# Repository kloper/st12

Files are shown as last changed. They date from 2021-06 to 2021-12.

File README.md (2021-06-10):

* README for ST12

I am working on my own soldering station based on HAKKO T12 cartriges. 
Electronics is related to the one found on EEVBlog forum
https://www.eevblog.com/forum/reviews/t12-stm32-v2-1s-soldering-station-controller-schematic-etc/

Firmware will be built from scratch.
Work in progress.

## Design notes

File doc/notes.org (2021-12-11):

* Unsorted Tasks

** TODO Disable station on overcurrent
   [2021-10-31 Sun 22:40]
   [[file:~/w/st12/firmware/st12_term.h::uint32_t current;]]

** TODO Move target temp increment to config
   [2021-10-31 Sun 22:51]
   [[file:~/w/st12/firmware/st12_term.c::config_set_target_temperature(config->target_temperature + 500);]]

* Notes for ST12 development

** Firmware work plan

  1. ADC in for I_SENSE
  2. ADC in for T_SENSE
  3. ADC in for cold junction thermistor
  4. Initial calibration for ADC inputs
  5. GPIO input for SHAKE_SENSE
  6. GPIO input for rotary encoder
  7. I2C interface with EEPROM
  8. I2C interface with Pato display controller
   
** Source of type-all.pdf

   https://www.tayloredge.com/reference/Tables/thermocouple01.pdf

** 24LC1052

I2C Address is 0x50 for block 0 and 0x54 for block 1
Address is 16 bit wide.
Write is 16bit address + data bytes
Read is 16bit address write + data bytes read

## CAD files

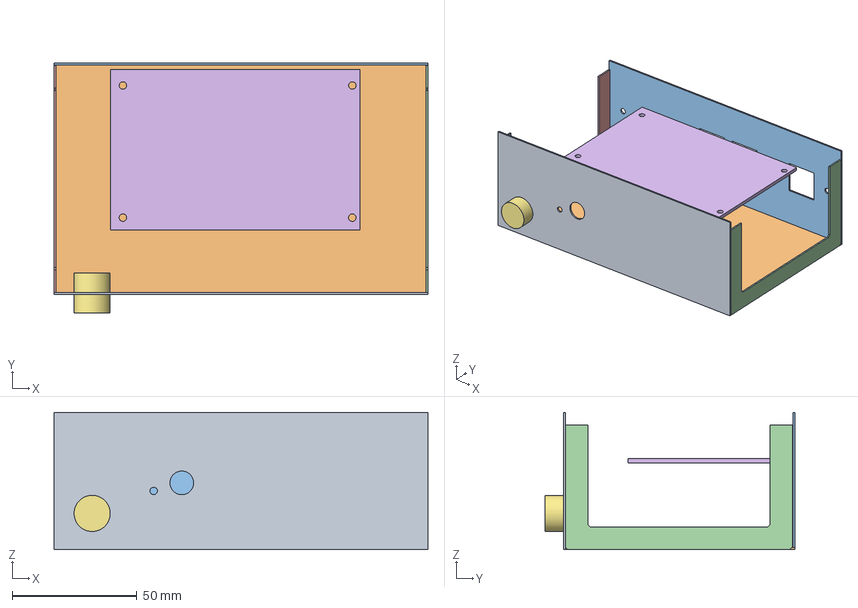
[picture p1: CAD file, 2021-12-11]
freecad/st12.FCStd
150.0 x 100.2 x 55.0 mm
front
bottom
back
right_side
left_side
pcb
heater

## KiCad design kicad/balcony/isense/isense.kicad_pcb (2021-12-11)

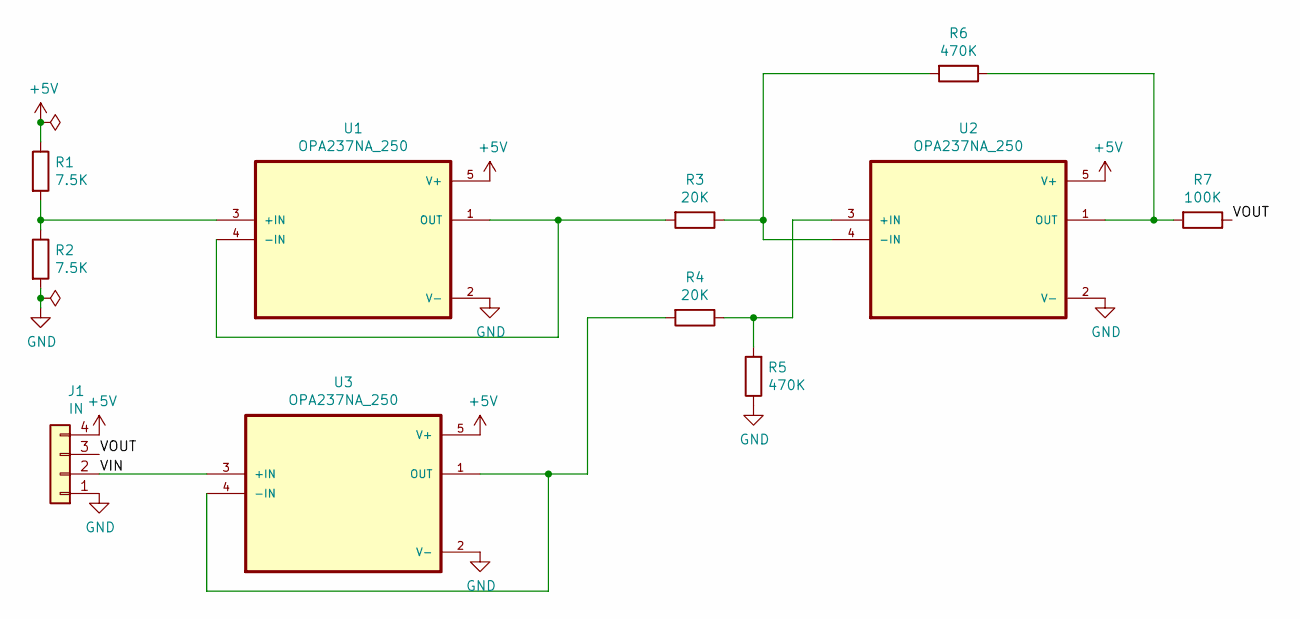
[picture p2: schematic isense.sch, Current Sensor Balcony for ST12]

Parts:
J1: IN; Pin_Header_Straight_1x04_Pitch2.54mm
R1, R2: 7.5K; R_0805_HandSoldering
R3, R4: 20K; R_0805_HandSoldering
R5, R6: 470K; R_1206_HandSoldering
R7: 100K; R_0805_2012Metric_Pad1.20x1.40mm_HandSolder
U1, U2, U3: OPA237NA_250; SOT95P280X145-5N

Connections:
+5V: J1.4, R1.1, U1.5 (V+), U2.5 (V+), U3.5 (V+)
/VIN: J1.2, U3.3 (+IN)
/VOUT: J1.3, R7.1
GND: J1.1, R2.2, R5.1, U1.2 (V-), U2.2 (V-), U3.2 (V-)
unnamed: R1.2, R2.1, U1.3 (+IN)
unnamed: R3.1, R6.2, U2.4 (-IN)
unnamed: R3.2, U1.1 (OUT), U1.4 (-IN)
unnamed: R4.1, R5.2, U2.3 (+IN)
unnamed: R4.2, U3.1 (OUT), U3.4 (-IN)
unnamed: R6.1, R7.2, U2.1 (OUT)

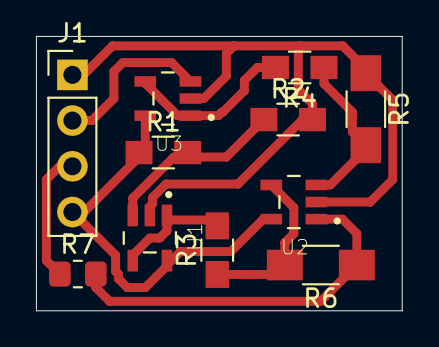
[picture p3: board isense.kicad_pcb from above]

Board: 2 copper layers, 20.3 x 15.2 mm, 11 parts (0 on the bottom side), 10 nets.

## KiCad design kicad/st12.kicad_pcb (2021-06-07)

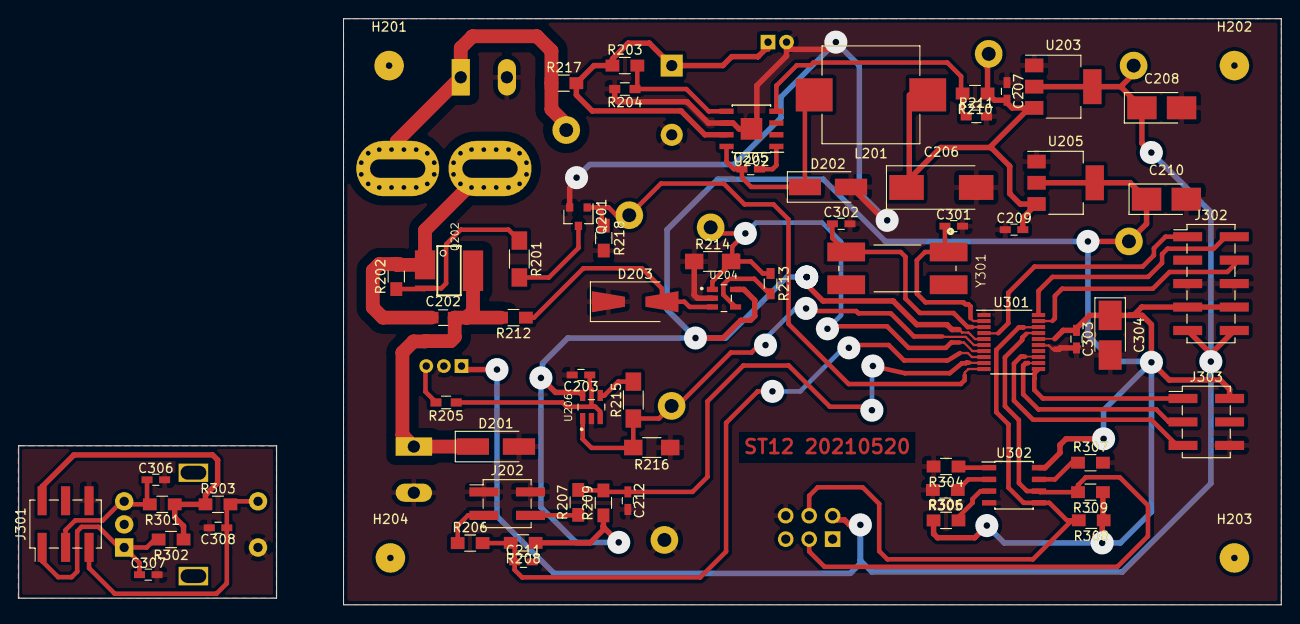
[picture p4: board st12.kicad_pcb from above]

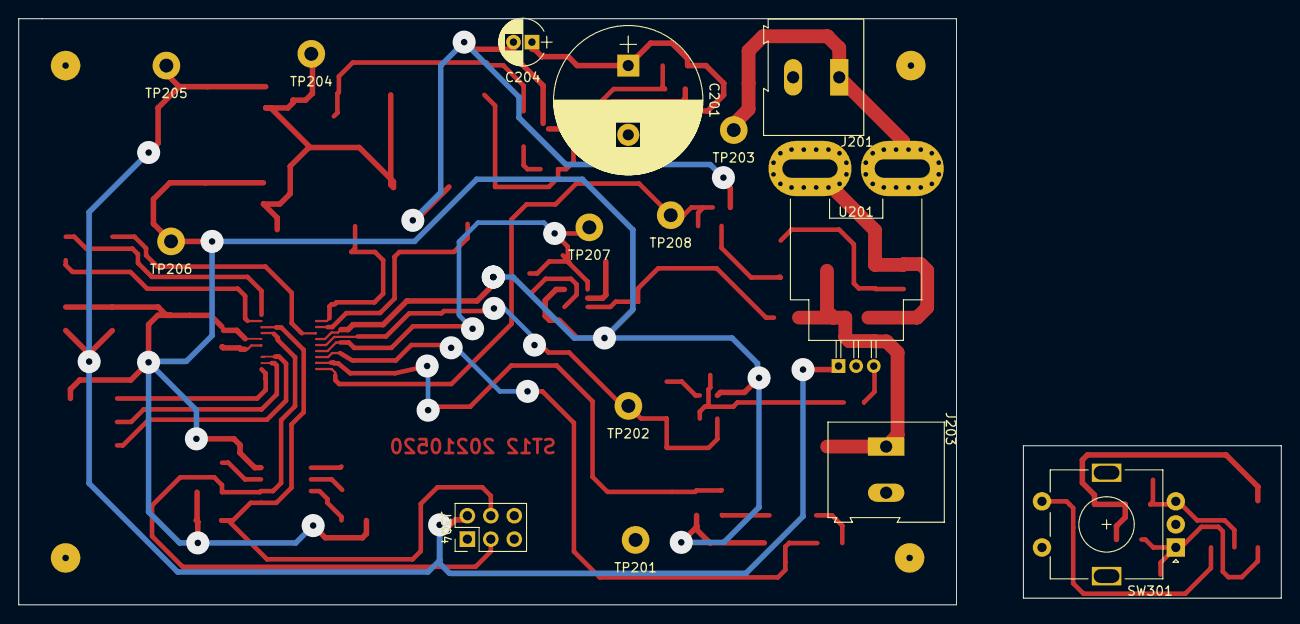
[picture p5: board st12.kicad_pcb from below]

Board: 2 copper layers, 101.6 x 63.5 mm, 81 parts (15 on the bottom side), 45 nets.

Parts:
C201: 220uF 35V; CP_Radial_D16.0mm_P7.50mm
C202: 1uF; C_0805_HandSoldering
C203, C207, C209, C303, C306, C307, C308: 100nF; C_0603_HandSoldering
C204: 10uF 35V; CP_Radial_D5.0mm_P2.00mm
C205, C211, C212: 10nF; C_0603_HandSoldering
C206: 220uF 6V; CP_Tantalum_Case-X_EIA-7343-43_Hand
C208, C210: 10uF; CP_Tantalum_Case-B_EIA-3528-21_Hand
C301, C302: 22pF; C_0603_HandSoldering
C304: 4.7uF; CP_Tantalum_Case-B_EIA-3528-21_Hand
D201, D202: 30V 0.5A; D_SMA_Handsoldering
D203: RS1M; D_SMA-SMB_Universal_Handsoldering
H201, H202, H203, H204: MountingHole; MountingHole_3.2mm_M3
J201: Conn_01x02_Male; TerminalBlock_Altech_AK300-2_P5.00mm
J202: T12_Sense; Pin_Header_Straight_2x02_Pitch2.54mm_SMD
J203: T12_POWER; TerminalBlock_Altech_AK300-2_P5.00mm
J301: ROT_OUT; Pin_Header_Straight_2x03_Pitch2.54mm_SMD
J302: DEBUG; Pin_Header_Straight_2x05_Pitch2.54mm_SMD
J303: ROT_IN; Pin_Header_Straight_2x03_Pitch2.54mm_SMD
J304: DISPLAY; Pin_Header_Straight_2x03_Pitch2.54mm
L201: 15uH; L_10.4x10.4_H4.8
Q201: 2N7002; SOT-23
Q202: FDS4435BZ; SO08-E3
R201, R214, R215, R216: 1K; R_1206_HandSoldering
R202: 2K; R_0805_HandSoldering
R203, R210: 100K; R_0805_HandSoldering
R204: 10K; R_0603_HandSoldering
R205: 47; R_0603_HandSoldering
R206, R207, R208, R209, R212, R218, R301, R302, R303, R304, R305, R306, R307, R308, R309: 7.5K; R_0805_HandSoldering
R211: 24K; R_0603_HandSoldering
R213: 249K; R_0603_HandSoldering
R217: 0; R_0805_HandSoldering
SW301: Encoder; RotaryEncoder_Alps_EC11E-Switch_Vertical_H20mm
TP201: GND; Measurement_Point_Round-TH_Big
TP202: ISENSE; Measurement_Point_Round-TH_Big
TP203: 24V; Measurement_Point_Round-TH_Big
TP204: 6V; Measurement_Point_Round-TH_Big
TP205: 5V; Measurement_Point_Round-TH_Big
TP206: 3.3V; Measurement_Point_Round-TH_Big
TP207: TSENSE; Measurement_Point_Round-TH_Big
TP208: CTRL; Measurement_Point_Round-TH_Big
U201: ACS756xCB-050B-PFF; Allegro_CB_PFF
U202: TPS5430DDAR; SOIC-8-1EP_3.9x4.9mm_Pitch1.27mm
U203: AMS1117-5.0; SOT-223-3_TabPin2
U204, U206: OPA237NA_250; SOT95P280X145-5N
U205: AMS1117-3.3; SOT-223-3_TabPin2
U301: STM32F030F4Px; TSSOP-20_4.4x6.5mm_Pitch0.65mm
U302: 24LC1025; SOIC-8_3.9x4.9mm_Pitch1.27mm
Y301: MA-506-8MHz; XTAL_MA-506_4.0000M-C3_ROHS

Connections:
+3V3: C210.1, C303.1, C304.1, J302.7, J302.8, J303.2, R208.1, R209.1, R306.1, R308.1, R309.1, TP206.1, U204.5, U205.2, U206.5, U301.5, U301.16, U302.8
+5V: C208.1, J302.9, J302.10, J304.2, TP205.1, U201.1, U203.2
+6V: C206.1, C207.2, C209.2, L201.1, R210.1, TP204.1, U203.3, U205.3
+24V: J201.1, R217.1, TP203.1, U201.4
/control/ROTA: C307.1, J301.1, R302.2, SW301.A
/control/ROTA_IN: J303.1, U301.11
/control/ROTB: C306.1, J301.3, R301.2, SW301.B
/control/ROTB_IN: J303.3, U301.12
/control/ROTP: C308.1, J301.5, R303.2, SW301.S1
/control/ROTP_IN: J303.5, U301.13
/control/ROT_GND: C306.2, C307.2, C308.2, J301.6, SW301.C, SW301.S2
/control/ROT_VCC: J301.2, R301.1, R302.1, R303.1
/control/SCL: J304.3, R309.2, U301.17, U302.6
/control/SDA: J304.4, R308.2, U301.18, U302.5
/control/SWCLK: J302.2, U301.20
/control/SWDIO: J302.4, U301.19
/control/~RST~: J302.1, U301.4
/power/COLD: J202.4, R207.1
/power/SHAKE: J202.3, R206.1
/power/V24AVAIL: R203.2, R204.1, U202.5
/power/V24HEATER: C202.2, D201.1, J203.1, Q202.58, R212.2
/power/V24SRC: C201.1, C204.1, R203.1, R217.2, U202.7
/power/VSENS: R210.2, R211.1, U202.4
COLD_SENSE: C212.1, R207.2, R209.2, U301.9
GND: C201.2, C203.2, C204.2, C206.2, C207.1, C208.2, C209.1, C210.2, C211.2, C212.2, C301.2, C302.2, C303.2, C304.2, D201.2, D202.2, D203.1, J201.2, J202.1, J202.2, J203.2, J302.5, J302.6, J303.6, J304.6, Q201.2, R204.2, R211.2, R214.1, R216.1, R218.2, R304.2, R305.2, R307.2, TP201.1, U201.2, U202.6, U202.9, U203.1, U204.2, U205.1, U206.2, U301.1, U301.15, U302.4
HEATER_CTL: Q201.1, R218.1, TP208.1, U301.10
I_SENSE: R215.1, R216.2, TP202.1, U206.1, U301.6
unnamed: C202.1, Q202.13, R202.2, U201.5
unnamed: C203.1, R205.1, U206.3
unnamed: C205.1, D202.1, L201.2, U202.8
unnamed: C205.2, U202.1
unnamed: C301.1, U301.2, Y301.1
unnamed: C302.1, U301.3, Y301.2
unnamed: D203.2, R212.1, U204.3
unnamed: Q201.3, R201.2
unnamed: Q202.4, R201.1, R202.1
unnamed: R205.2, U201.3
unnamed: R213.2, U204.4
unnamed: R215.2, U206.4
unnamed: R304.1, U302.1
unnamed: R305.1, U302.2
unnamed: R306.2, U302.3
unnamed: R307.1, U302.7
SHAKE_SENSE: C211.1, R206.2, R208.2, U301.8
T_SENSE: R213.1, R214.2, TP207.1, U204.1, U301.7

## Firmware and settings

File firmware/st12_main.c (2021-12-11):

/* -*- C -*-
 *
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
 * Copyright (c) 2021 Dimitry Kloper <kloper@users.sf.net>
 *
 * main.c -- Main file for ST12
 *
 */
#include <stdlib.h>
#include <string.h>
#include <stdio.h>

#include <libopencm3/stm32/adc.h>
#include <libopencm3/stm32/rcc.h>

#include "st12.h"
#include "st12_config.h"
#include "st12_adc.h"
#include "st12_dma.h"
#include "st12_gpio.h"
#include "st12_ptimer.h"
#include "st12_temp.h"
#include "st12_i2c.h"
#include "st12_display.h"
#include "st12_rotary.h"
#include "st12_current.h"
#include "st12_shake.h"
#include "st12_term.h"
#include "st12_menu.h"

typedef enum _main_loop_state {
  STATE_HEATING,
  STATE_MEASURE_WAIT  
} main_loop_state_t;

int main(void) {
  const st12_config_t *config = NULL;

  //rcc_clock_setup_in_hse_8mhz_out_48mhz();
  rcc_clock_setup_in_hsi_out_48mhz();
  gpio_init();
  dma_init();
  adc_init();
  i2c_init();
  rotary_init();
  periodic_timer_init();
  config_init();

  config = config_get();
  
  adc_start_conversion_regular(ADC1);

  st12_adc_values_t adc_state = {0};
  main_loop_state_t state = STATE_HEATING;
  uint32_t idle_state_count = 0;
  uint32_t wait_state_count = 0;
  uint32_t print_count = 0;
  uint32_t prev_count = 0;
  uint32_t count = 0;
  int32_t rotary_counter = 0;
  uint32_t rotary_press_counter = 0;

  term_st12_temp_label_t st12_temp_label;
  term_st12_menu_t st12_menu;  
  term_frame_t root_frame;
  int disable_heater = 0;
  
  term_st12_temp_label_init(&st12_temp_label, config);
  term_st12_menu_init(&st12_menu);
  term_frame_init(&root_frame);

  term_frame_add_child(&root_frame, (term_widget_t*)&st12_temp_label, 1);
  term_frame_add_child(&root_frame, (term_widget_t*)&st12_menu, 0);
  
  while (1) {
    if( print_count++ % 2000 == 0 ) {      
      display_ctrl(1, 0, 0);
      term_frame_render(&root_frame);
    }
    
    periodic_timer_get_state(&adc_state);

    count = adc_state.count - prev_count;
    prev_count = adc_state.count;

    st12_temp_label.current = current_convert(config, &adc_state);

    // overcurrent protection
    if(st12_temp_label.current >= 2600) {
      gpio_heater_control(0);          
      disable_heater = 1;
      st12_temp_label.overcurrent = 1;
    }
    
    switch(state) {
      case STATE_HEATING: {
        idle_state_count += count;
        if(idle_state_count >= config->overshoot_period_width) {
          idle_state_count = 0;
          gpio_heater_control(0);          
          state = STATE_MEASURE_WAIT;
        }
      } break;
      case STATE_MEASURE_WAIT: {
        wait_state_count += count;
        if(wait_state_count >= config->measure_period_width) {
          wait_state_count = 0;
          st12_temp_label.temperature = temp_convert(config, &adc_state);
          if(!disable_heater &&
             st12_temp_label.temperature <=
             shake_get_temperature(config, &st12_temp_label.is_idle))
          {            
            gpio_heater_control(1);
            //gpio_heater_control(0);
            state = STATE_HEATING;                      
          }
        }
      } break;        
    }

    int32_t counter = rotary_get_counter();

    if(counter < rotary_counter) {
      term_frame_dispatch(&root_frame, BACKWARD, rotary_counter - counter);
      rotary_counter = counter; 
    }

    if(counter > rotary_counter) {
      term_frame_dispatch(&root_frame, FORWARD, counter - rotary_counter);
      rotary_counter = counter; 
    }
    
    uint32_t press_counter = rotary_get_press_counter();
    if(press_counter > rotary_press_counter) {
      term_frame_dispatch(&root_frame, PRESS,
                          press_counter - rotary_press_counter);
      rotary_press_counter = press_counter; 
    }
    
    __asm__("wfi");
  }
}

/*
 * end of file
 */

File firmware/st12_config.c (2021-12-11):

/* -*- C -*-
 *
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
 * Copyright (c) 2021 Dimitry Kloper <kloper@users.sf.net> 
 *
 * st12_config.c -- ST12 persistent configuration, based on EEPROM
 *
 */
#include <string.h>

#include <libopencm3/stm32/rcc.h>
#include <libopencm3/stm32/i2c.h>
#include <libopencm3/stm32/crc.h>

#include "st12.h"
#include "st12_config.h"
#include "st12_i2c.h"

#define CONFIG_I2C_OFFSET 0
#define CONFIG_I2C_ADDR 0x50
#define CONFIG_I2C_BADDR 0x54

typedef struct _st12_config_packet {
  uint16_t alignment_bytes1;
  uint16_t addr;
  st12_config_t config;
  uint32_t alignment_bytes2;
} st12_config_packet_t;

static st12_config_packet_t g_config_packet = {0};
static st12_config_t *g_config = &g_config_packet.config;

static uint32_t config_get_crc(void) {
  crc_reset();
  return crc_calculate_block(
      (uint32_t*)((uint8_t*)g_config + sizeof(g_config->crc)),
      (sizeof(st12_config_t) -
       sizeof(g_config->crc) +
       sizeof(uint32_t) - 1) / sizeof(uint32_t)
  );
}

static void config_default(void) {
  g_config->version = CONFIG_VERSION;
  g_config->target_temperature = 100000; // Milli-Celsius
  g_config->overshoot_period_width = 300; // milliseconds (periodic timer period)
  g_config->measure_period_width = 50; // milliseconds (periodic timer period)
  g_config->temp_scale = 840; // multiply ADC clicks (corresponding to mV)
                              // by 0.840 before temperature conversion
  g_config->temp_offset = 8; // offset ADC clicks before
                             // temperature conversion
  g_config->current_scale = 4000; // multiply ADC clicks (corresponding to mV)
                                  // before current conversion
  g_config->current_offset = 0; // offset ADC clicks before current conversion
  g_config->idle_timeout = 20000; // 20 Seconds in ticks of periodic timer
  g_config->idle_temperature = 120000; // 120C when idle
  g_config->crc = config_get_crc();
}

void config_save(void) {
  i2c_send(CONFIG_I2C_ADDR,
           (uint8_t*)&g_config_packet.addr,
           sizeof(g_config_packet.addr) + sizeof(g_config_packet.config),
           1);
}

const st12_config_t *config_get(void) {
  return g_config;
}

void config_init() {
  rcc_periph_clock_enable(RCC_CRC);

  g_config_packet.addr = FLASH_ADDR(CONFIG_I2C_OFFSET);
  i2c_send(CONFIG_I2C_ADDR,
           (uint8_t*)&g_config_packet.addr,
           sizeof(g_config_packet.addr),
           0);
  i2c_recv(CONFIG_I2C_ADDR,
           (uint8_t*)&g_config_packet.config,
           sizeof(g_config_packet.config));
  uint32_t crc = config_get_crc();
  if(crc != g_config->crc || g_config->version != CONFIG_VERSION) {
    config_default();
    config_save();
  }
}

static struct {
  uint16_t alignment_bytes1;
  uint16_t addr;
  uint8_t  data[sizeof(uint32_t)];
  uint32_t alignment_bytes2;
} g_packet;

static void config_write_uint32(size_t offset) {

  g_packet.addr = FLASH_ADDR(CONFIG_I2C_OFFSET + offset);
  *(uint32_t*)g_packet.data = *(uint32_t*)((char*)g_config + offset);

  i2c_send(CONFIG_I2C_ADDR,
           (uint8_t*)&g_packet.addr,
           sizeof(g_packet.addr) + sizeof(uint32_t),
           1
  );

  for(int i = 0; i < 100000; i++) {
    __asm__("nop");
  }
  
  g_packet.addr = FLASH_ADDR(CONFIG_I2C_OFFSET);
  *(uint32_t*)g_packet.data = g_config->crc;

  i2c_send(CONFIG_I2C_ADDR,
           (uint8_t*)&g_packet.addr,
           sizeof(g_packet.addr) + sizeof(uint32_t),
           1
  );

  for(int i = 0; i < 100000; i++) {
    __asm__("nop");
  }

}

void config_set_target_temperature(int32_t temp) {
  g_config->target_temperature = temp;
  g_config->crc = config_get_crc();
  config_write_uint32(offsetof(st12_config_t, target_temperature));
}

void config_set_temperature_scale(uint32_t scale) {
  g_config->temp_scale = scale;
  g_config->crc = config_get_crc();
  config_write_uint32(offsetof(st12_config_t, temp_scale));
}

void config_set_temperature_offset(int32_t offset) {
  g_config->temp_offset = offset;
  g_config->crc = config_get_crc();
  config_write_uint32(offsetof(st12_config_t, temp_offset));
}

void config_set_overshoot_period_width(uint32_t width) {
  g_config->overshoot_period_width = width;
  g_config->crc = config_get_crc();  
  config_write_uint32(offsetof(st12_config_t, overshoot_period_width));
  
}

void config_set_measure_period_width(uint32_t width) {
  g_config->measure_period_width = width;
  g_config->crc = config_get_crc();    
  config_write_uint32(offsetof(st12_config_t, measure_period_width));
}

void config_set_current_scale(uint32_t scale) {
  g_config->current_scale = scale;
  g_config->crc = config_get_crc();
  config_write_uint32(offsetof(st12_config_t, current_scale));
}

void config_set_current_offset(int32_t offset) {
  g_config->current_offset = offset;
  g_config->crc = config_get_crc();
  config_write_uint32(offsetof(st12_config_t, current_offset));
}

void config_set_idle_temperature(int32_t temp) {
  g_config->idle_temperature = temp;
  g_config->crc = config_get_crc();
  config_write_uint32(offsetof(st12_config_t, idle_temperature));
}

void config_set_idle_timeout(uint32_t timeout) {
  g_config->idle_timeout = timeout;
  g_config->crc = config_get_crc();
  config_write_uint32(offsetof(st12_config_t, idle_timeout));
}

/* 
 * end of file
 */

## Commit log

2021-06-07 Initial import of ST12 kicad files.
    [control.sch, power.sch, st12.kicad_pcb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]
2021-06-10 Add current sensor balcony patch
    [isense.kicad_pcb, isense.sch]
2021-06-10 Add BMP->ST-Link2 debug adapter
    [bmp_debug_adapter.kicad_pcb, bmp_debug_adapter.sch]
2021-06-10 Fix ST12 schematics with current sensor (tested on balcony patch)
    [control.sch, isense.sch, power.sch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]
2021-06-10 Move all kicad stuff under kicad folder
    [bmp_debug_adapter.kicad_pcb, bmp_debug_adapter.sch, control.sch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]
2021-06-18 Implement input ADC management with DMA and periodic timer
2021-07-07 ADC code fixes + temperature calculations
    [main.c, st12_adc.c, st12_adc.h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]
2021-07-12 Start to implement proper exception management ...
    At this stage introduce own blocking handler for unmanaged
    exceptions. This one differs from handler provided by cm3
    by keeping exception number in local variable.
    Remove invocation of HSE, stay on HSI and 48MHz PLL. Switching
    to external clock quite frequently causes hard fault exceptions
    for unknown reason.
2021-07-12 Introduce I2C initialization and persistent configuration ...
    The persistent configuration is based on I2C attached EEPROM.
    The config is implemented as a structure in memory with write
    through functionality.
2021-07-18 Fixes in schematics (only) done during initial debug
    [control.sch, isense.sch, power.sch]
2021-07-18 Introduce pato display support and rotary encoder support
2021-09-28 Decrease speed of I2C bus to 50KHz
    For yet unknown reason, STM32 interface gets NACKS from Pato display
    on startup, this leads libopencm3 I2C implentation to stall on I2C
    communication.
    Decreasing speed of the bus decreases chances of NACKS.
    [st12_i2c.c]
2021-09-28 Factor out I2C send and receive operations to be generic I2C code.
2021-09-28 Fix EEPROM memory address endian.
    Write and read operations to I2C EEPROM start from I2C write with two byte
    memory address of the desired operation. The address must be big endian.
    [st12_config.c]
2021-09-28 Introduce initial code for current monitoring.
2021-09-28 Introduce scale and offset for temperature conversion
2021-10-01 Introduce current scale and offset config parameters ...
    For fine tuning of the current measurement
2021-10-02 Remove read part of the query when printing on display ...
    Since latest pato USI does not require read transaction after write
    we can remove reading of unneeded info.
2021-10-02 Introduce support for ST12 handle shake sensor ...
    The shake sensor is simple mercury bulb that shorts middle point
    of 7.5K/7.5K voltage divider to ground. It is also connected to
    PA2. We use it in fashion similar to rotary encoder - declare
    PA2 as external interrupt source and just counting events on
    the line.
    [main.c, st12_gpio.c, st12_nvic.c]
2021-10-23 Introduce config version ...
    Config version is included in total CRC calculation.
    Thus, bumping version causes the EEPROM reset to factory settings.
    [st12_config.c]
2021-10-23 Improve idle sensor detection and temperature drop
    This change causes temperature drop upon reaching idle state after
    predefined timeout. The idle state is canceled once shake sensor
    state change is detected.
2021-10-28 Remove "extern" from function prototypes in header files
2021-10-30 Change printing format and remove redundant printing conditions
2021-10-30 Add spin-off of term code from uv-timer
2021-10-31 Introduce temperature/current info widget
    Substitute regular print with similar functionality based on term library.
    The term_st12_temp_label_t now holds idle, temperature and current variables
    and is responsible for handling top line on the display.
    Rotary encoder events are now handled by widgets.
2021-11-17 Bump version and add version check to reset config on bump
    [st12_config.c]
2021-11-17 Fix missing ending zero when sending data to display
    Pato protocol requires print data to end with zero character.
    ST12 display code could miss sending the last zero on even
    number of chars in the print string
    [st12_display.c]
2021-12-11 Add over-current indication support
2021-12-11 Various schematic fixes
    [isense.kicad_pcb, isense.sch, power.sch]
2021-12-11 Add freecad case project
    [st12.FCStd]

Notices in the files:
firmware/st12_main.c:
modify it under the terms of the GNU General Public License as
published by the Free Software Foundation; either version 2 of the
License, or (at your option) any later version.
